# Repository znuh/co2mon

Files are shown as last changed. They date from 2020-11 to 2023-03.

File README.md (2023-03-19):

# CO2 multimon

CO2 monitor with support for different sensors, displays and microcontrollers.

Firmware and the printed circuit board include support for all of these components.
No special boards or firmware versions are needed. Sensors and the display are automatically detected by the firmware.

## Supported CO2 sensors
* SCD30
* MH-Z14A, MH-Z19B
* T67xx

## Supported displays
* 1.8" SPI TFT (ST7735 controller)
* 1.3" OLED (**must** have the following pinout: Vdd, GND, SCK, SDA - most 0.96" OLED displays will not work!)
**Note:** Try to get the 1.8" TFT instead of the OLED. OLED displays will 'burn out' after approx. 1 month of continous use. Therefor OLED support is meant as a makeshift if you cannot get the TFT.

## Supported microcontrollers

### ATMega328P 'Nano V3' Boards
For this variant you need to solder a few 0805 resistors and 3x SOT-23 components to side B of the PCB.

### STM32F042K6T6 
Fot this variant you need to solder the LQFP-32 controller, a SOT-23 component, the micro-USB connector, a 1210 fuse and a few 0603 passives to side A of the PCB.

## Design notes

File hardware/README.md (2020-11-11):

## further ideas
* add Vdd/GND labels to OLED connector
* use other micro-USB connector? (current choice is hard to solder by hand)
* 3D printed case? (might need larger PCB?)
* add-on board for temp./humidity

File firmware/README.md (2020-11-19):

# building for ATMega328P target
* make sure you have *avr-gcc + libc and binutils* installed
* run **make avr**

## flashing the ATMega328P
* make sure *avrdude* is installed
* run **avrdude -pm328p -carduino -b57600 -P /dev/ttyUSBx -Uflash:w:co2mon.hex:i** (replace ttyUSBx with your device)

# building for STM32F042K target
* make sure you have the *arm-none-eabi* toolchain installed
* get *libopencm3* with **git submodule init && git submodule update**
* build libopencm3 with **make -j8 -C libopencm3**
* run **make stm32**

## flashing the STM32
* **NOTE:** MH-Zxx sensors must be disconnected before starting the bootloader (otherwise the STM32 bootloader will try talking to the MH-Z sensor and USB will not work)
* make sure *dfu-util* is installed
* set the *BOOT_SEL* jumper (JP1) before connecting the board to your computer
* run **dfu-util -a 0 --dfuse-address 0x08000000 -D co2mon.bin**

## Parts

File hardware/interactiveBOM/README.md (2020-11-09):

# BOMs
* use **atmega328p-ibom.html** for ATMega328P variant
* use **stm32-ibom.html** for STM32 variant

**Note:** The BOMs include **all** pin sockets. You only need to place those used by your sensor and display.

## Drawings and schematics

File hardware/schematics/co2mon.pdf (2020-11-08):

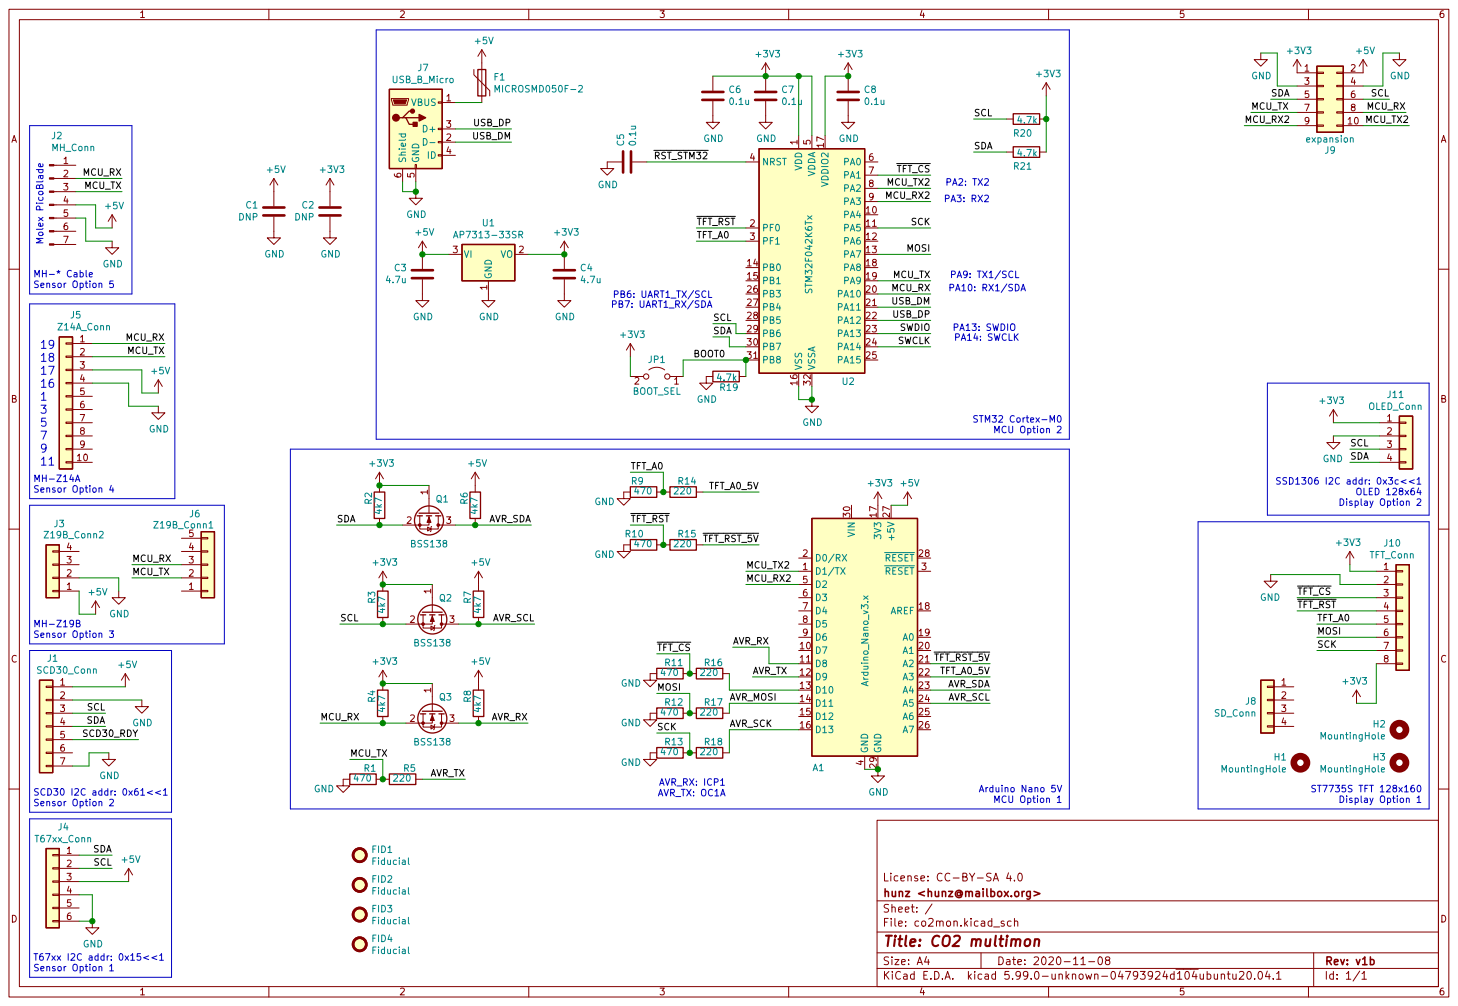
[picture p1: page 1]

1 PA4 10 PA5 11 PA6 12 PA7 13 PB0 14 PB1 15 VSS 16 VDDIO2 17 PA8 18 PA9 19 PF0 2 PA10 20 PA11 21 PA12 22 PA13 23 PA14 24 PA15 25 PB3 26 PB4 27 PB5 28 PB6 29 PF1 3 PB7 30 PB8 31 VSSA 32 NRST 4 VDDA

License: CC-BY-SA 4.0 R18

File: co2mon.kicad_sch Sheet: / hunz <hunz@mailbox.org>

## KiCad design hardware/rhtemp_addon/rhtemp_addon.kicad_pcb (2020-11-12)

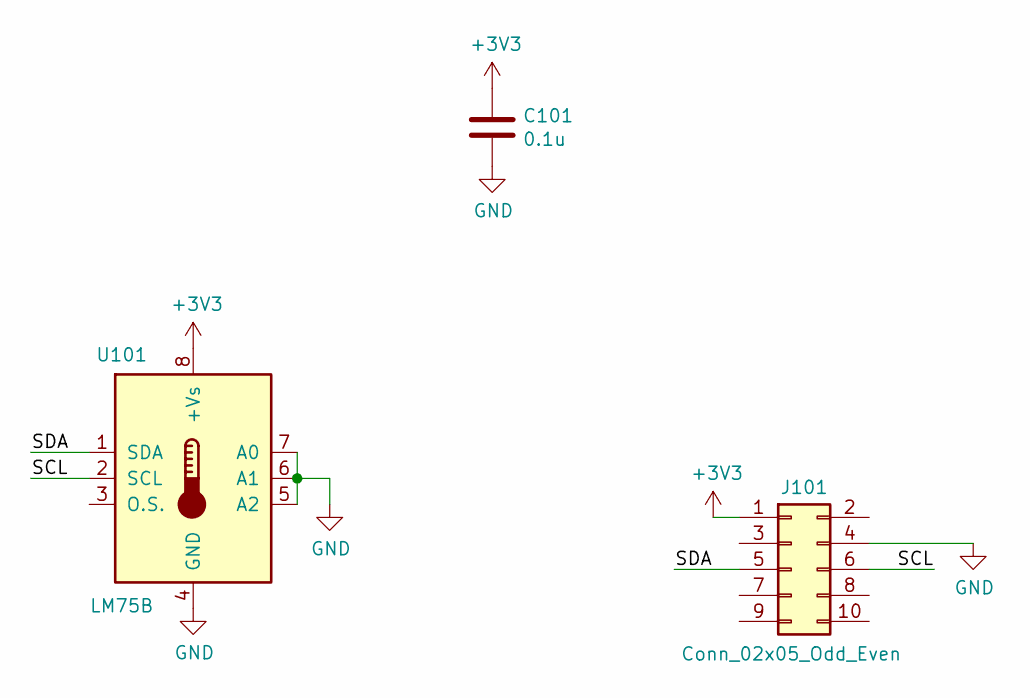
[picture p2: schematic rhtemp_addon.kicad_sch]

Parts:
C101: 0.1u; C_0603_1608Metric
J101: Conn_02x05_Odd_Even; PinSocket_2x05_P2.54mm_Vertical
U101: LM75B; SOIC-8_3.9x4.9mm_P1.27mm

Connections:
+3V3: C101.1, J101.1, U101.8 (+Vs)
/SCL: J101.6, U101.2 (SCL)
/SDA: J101.5, U101.1 (SDA)
GND: C101.2, J101.4, U101.4 (GND), U101.5 (A2), U101.6 (A1), U101.7 (A0)

Board: 2 copper layers, 3 parts (1 on the bottom side), 4 nets, no tracks yet.

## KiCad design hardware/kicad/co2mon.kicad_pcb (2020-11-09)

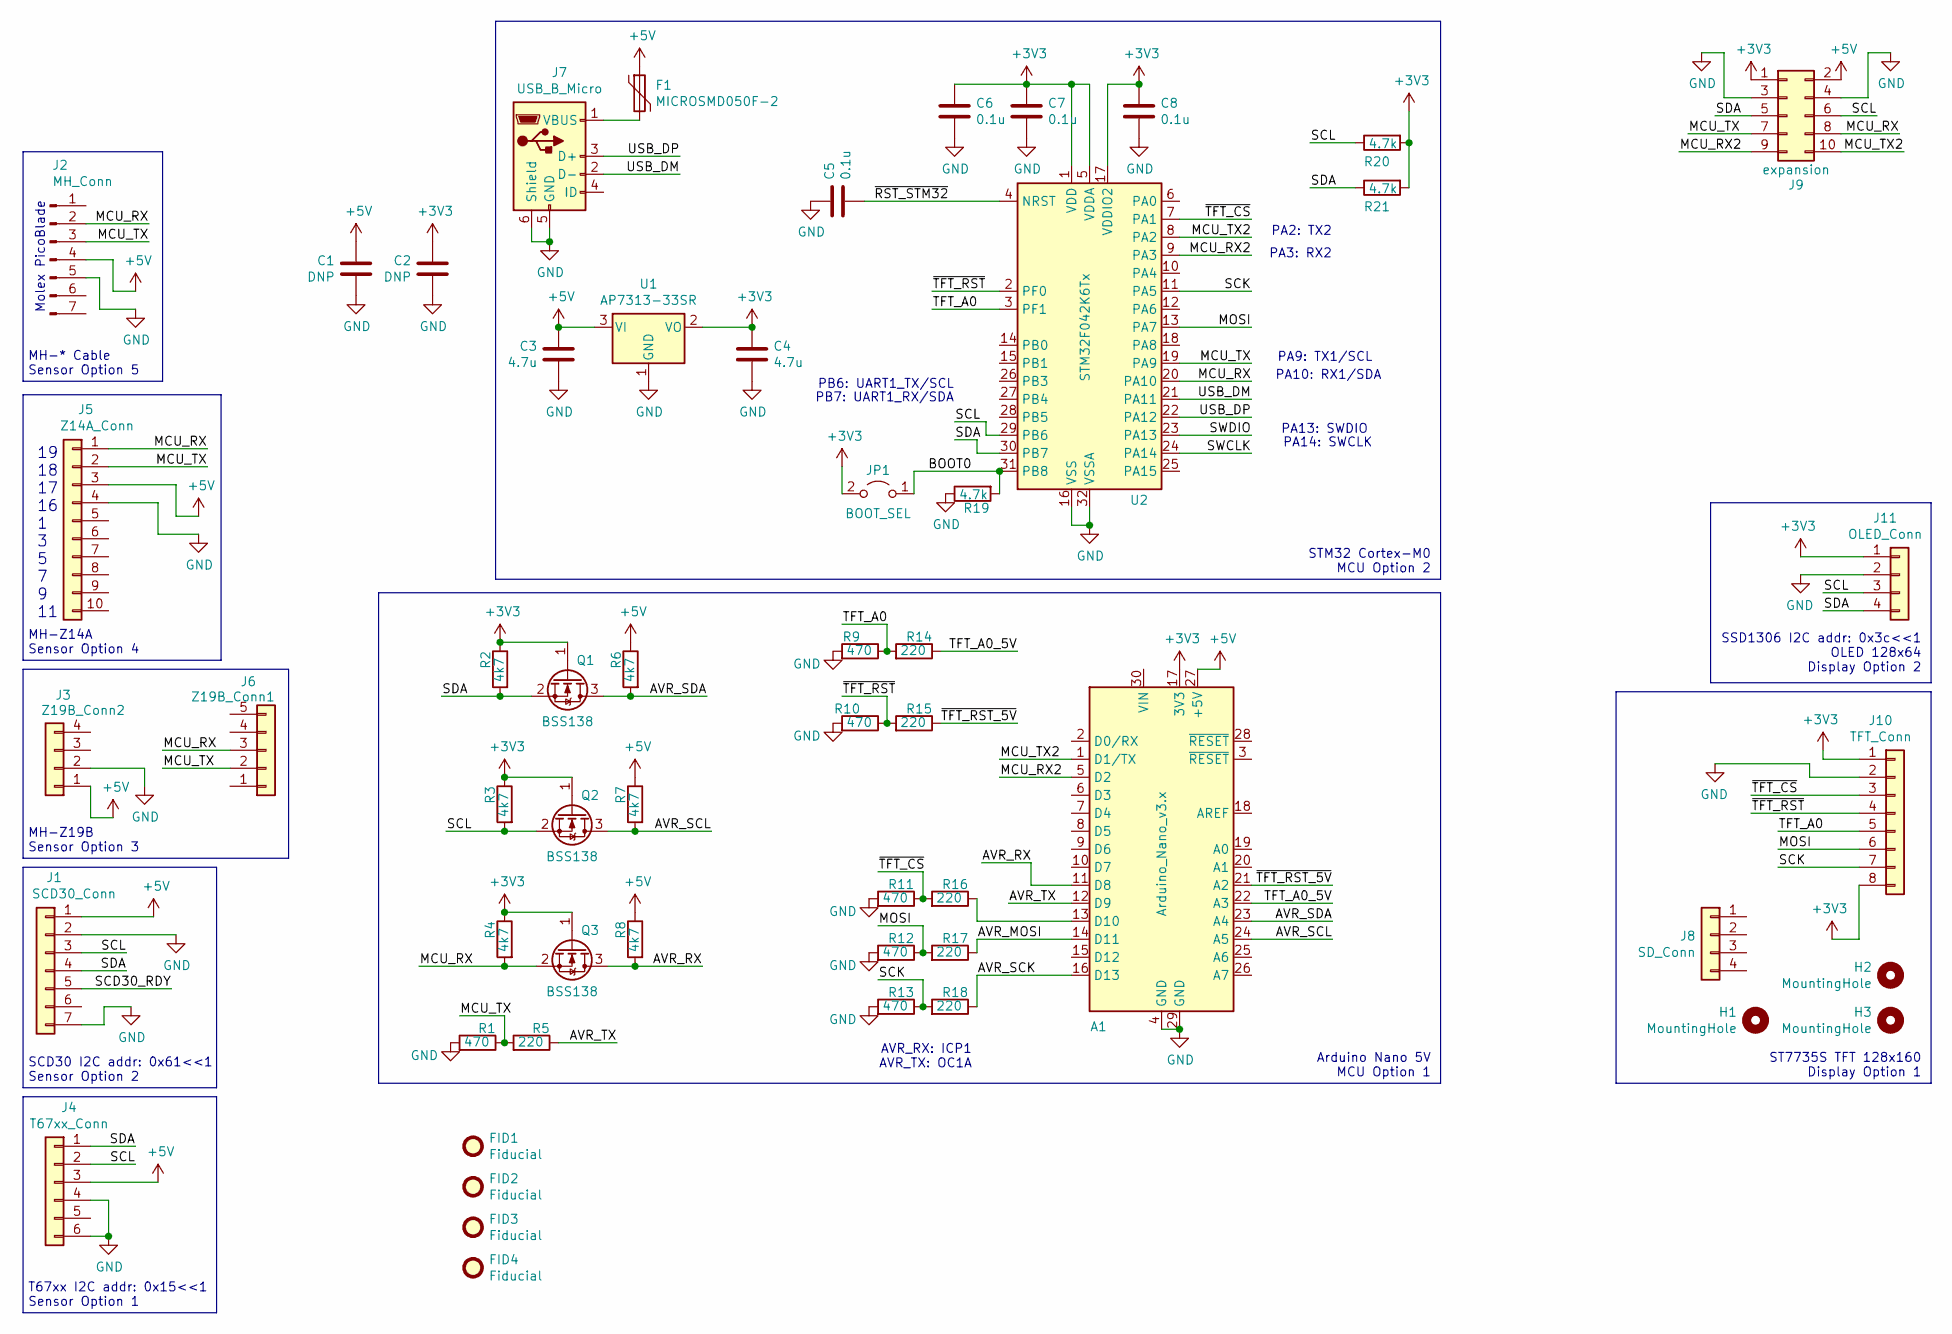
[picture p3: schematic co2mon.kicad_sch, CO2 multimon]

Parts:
A1: Arduino_Nano_v3.x; Arduino_Nano
C1, C2: DNP; C_0805_2012Metric_Pad1.15x1.40mm_HandSolder
C3, C4: 4.7u; C_0603_1608Metric
C5, C6, C7, C8: 0.1u; C_0603_1608Metric
F1: MICROSMD050F-2; Fuse_1210_3225Metric
FID1, FID2, FID3, FID4: Fiducial; Fiducial_0.5mm_Mask1.5mm
H1, H2, H3: MountingHole; MountingHole_3.2mm_M3
J1: SCD30_Conn; PinSocket_1x07_P2.54mm_Vertical
J2: MH_Conn; Molex_PicoBlade_53048-0710_1x07_P1.25mm_Horizontal
J3: Z19B_Conn2; PinSocket_1x04_P2.54mm_Vertical
J4: T67xx_Conn; PinSocket_1x06_P2.54mm_Vertical
J5: Z14A_Conn; PinSocket_1x10_P2.54mm_Vertical
J6: Z19B_Conn1; PinSocket_1x05_P2.54mm_Vertical
J7: USB_B_Micro; USB_Micro-B_Molex-105017-0001
J8: SD_Conn; PinSocket_1x04_P2.54mm_Vertical
J9: expansion; PinHeader_2x05_P2.54mm_Vertical
J10: TFT_Conn; PinSocket_1x08_P2.54mm_Vertical
J11: OLED_Conn; PinSocket_1x04_P2.54mm_Vertical
JP1: BOOT_SEL; PinHeader_1x02_P2.54mm_Vertical
Q1, Q2, Q3: BSS138; SOT-23
R1, R9, R10, R11, R12, R13: 470; R_0805_2012Metric_Pad1.15x1.40mm_HandSolder
R2, R3, R4, R6, R7, R8: 4k7; R_0805_2012Metric_Pad1.15x1.40mm_HandSolder
R5, R14, R15, R16, R17, R18: 220; R_0805_2012Metric_Pad1.15x1.40mm_HandSolder
R19, R20, R21: 4.7k; R_0603_1608Metric
U1: AP7313-33SR; SOT-23
U2: STM32F042K6Tx; LQFP-32_7x7mm_P0.8mm

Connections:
+3V3: A1.17 (3V3), C2.2, C4.2, C6.2, C7.2, C8.2, J9.1, J10.1, J10.8, J11.1, JP1.2 (B), Q1.1 (G), Q2.1 (G), Q3.1 (G), R2.1, R3.1, R4.1, R20.2, R21.2, U1.2 (VO), U2.1 (VDD), U2.5 (VDDA), U2.17 (VDDIO2)
+5V: A1.27 (+5V), C1.2, C3.2, F1.1, J1.1, J2.4, J3.1, J4.3, J5.3, J9.2, R6.1, R7.1, R8.1, U1.3 (VI)
/AVR_MOSI: A1.14 (D11), R17.1
/AVR_RX: A1.11 (D8), Q3.3 (D), R8.2
/AVR_SCK: A1.16 (D13), R18.1
/AVR_SCL: A1.24 (A5), Q2.3 (D), R7.2
/AVR_SDA: A1.23 (A4), Q1.3 (D), R6.2
/AVR_TX: A1.12 (D9), R5.1
/BOOT0: JP1.1 (A), R19.2, U2.31 (PB8)
/MCU_RX: J2.2, J5.1, J6.3, J9.8, Q3.2 (S), R4.2, U2.20 (PA10)
/MCU_RX2: A1.5 (D2), J9.9, U2.9 (PA3)
/MCU_TX: J2.3, J5.2, J6.2, J9.7, R1.1, R5.2, U2.19 (PA9)
/MCU_TX2: A1.1 (D1/TX), J9.10, U2.8 (PA2)
/MOSI: J10.6, R12.1, R17.2, U2.13 (PA7)
/SCD30_RDY: J1.5
/SCK: J10.7, R13.1, R18.2, U2.11 (PA5)
/SCL: J1.3, J4.2, J9.6, J11.3, Q2.2 (S), R3.2, R20.1, U2.29 (PB6)
/SDA: J1.4, J4.1, J9.5, J11.4, Q1.2 (S), R2.2, R21.1, U2.30 (PB7)
/SWCLK: U2.24 (PA14)
/SWDIO: U2.23 (PA13)
/TFT_A0: J10.5, R9.1, R14.2, U2.3 (PF1)
/TFT_A0_5V: A1.22 (A3), R14.1
/USB_DM: J7.2 (D-), U2.21 (PA11)
/USB_DP: J7.3 (D+), U2.22 (PA12)
/~RST_STM32: C5.1, U2.4 (NRST)
/~TFT_CS: J10.3, R11.1, R16.2, U2.7 (PA1)
/~TFT_RST: J10.4, R10.1, R15.2, U2.2 (PF0)
/~TFT_RST_5V: A1.21 (A2), R15.1
GND: A1.4 (GND), A1.29 (GND), C1.1, C2.1, C3.1, C4.1, C5.2, C6.1, C7.1, C8.1, J1.2, J1.7, J2.5, J3.2, J4.4, J4.6, J5.4, J7.5 (GND), J7.6 (Shield), J9.3, J9.4, J10.2, J11.2, R1.2, R9.2, R10.2, R11.2, R12.2, R13.2, R19.1, U1.1 (GND), U2.16 (VSS), U2.32 (VSSA)
unnamed: A1.13 (D10), R16.1
unnamed: F1.2, J7.1 (VBUS)

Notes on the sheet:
MH-* Cable Sensor Option 5
MH-Z14A Sensor Option 4
MH-Z19B Sensor Option 3
SCD30 I2C addr: 0x61<<1 Sensor Option 2
T67xx I2C addr: 0x15<<1 Sensor Option 1
19 18 17 16 1 3 5 7 9 11
Molex PicoBlade
PB6: UART1_TX/SCL
PB7: UART1_RX/SDA
AVR_RX: ICP1 AVR_TX: OC1A
PA2: TX2
PA3: RX2
PA13: SWDIO
PA9: TX1/SCL
PA14: SWCLK
PA10: RX1/SDA
STM32 Cortex-M0 MCU Option 2
Arduino Nano 5V MCU Option 1
SSD1306 I2C addr: 0x3c<<1 OLED 128x64 Display Option 2
ST7735S TFT 128x160 Display Option 1

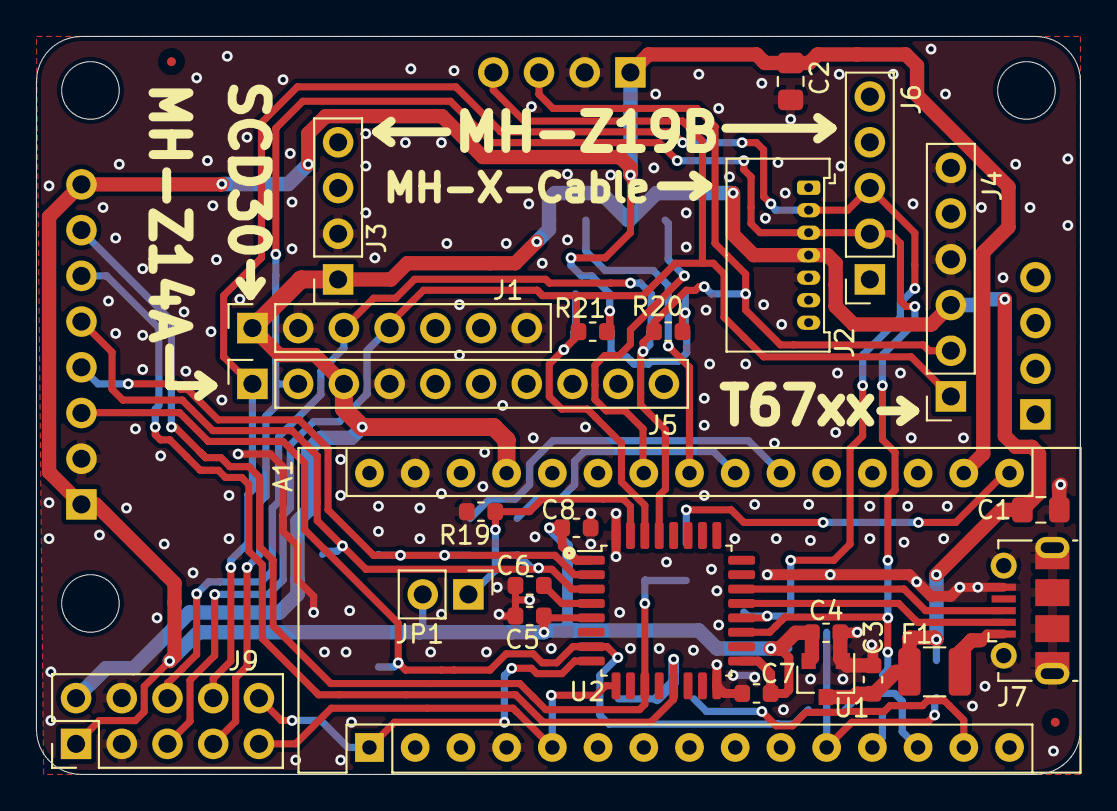
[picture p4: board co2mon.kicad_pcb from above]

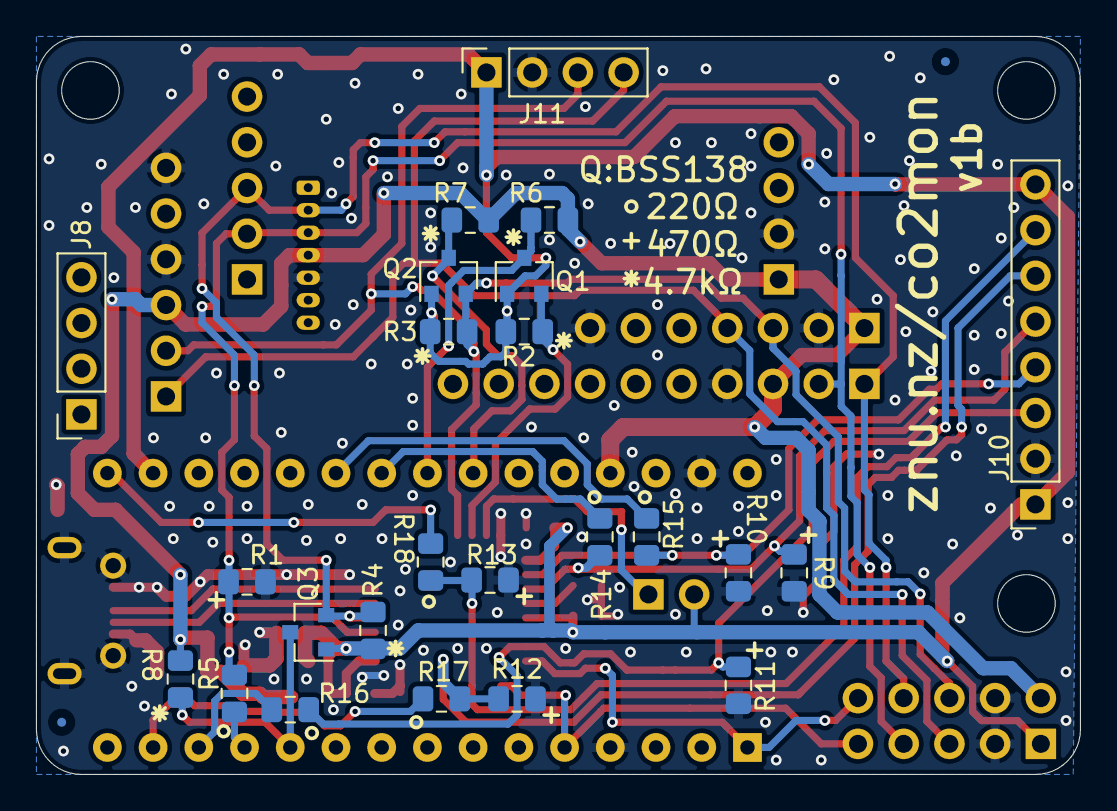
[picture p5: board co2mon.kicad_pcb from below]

Board: 2 copper layers, 58.0 x 41.0 mm, 55 parts (26 on the bottom side), 28 nets.

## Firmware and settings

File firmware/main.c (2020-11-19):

/*
 * This file is part of the co2mon project.
 *
 * Copyright (C) 2020 Benedikt Heinz <hunz@mailbox.org>
 *
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
 * You should have received a copy of the GNU General Public License
 * along with this code.  If not, see <http://www.gnu.org/licenses/>.
 */
#include "platform.h"
#include "sensors.h"
#include "display.h"
#include "utils.h"
#include <string.h>

/* maximum string length for both displays is 13 chars 
 * maximum number of lines for both displays is *4* */
#define PROJECT_STRING    "znu.nz/co2mon"
/* length of platform string (defined in Makefile) must be <= 10,
 * firmware string length must be <= 10 */
#define FIRMWARE_STRING   "v0.1-rc3"

static void print_info(void) {
	char display[14]="display: ";
	char sensors[3][14]={"","",""};
	char *lines[8]={
		PROJECT_STRING,
		"hw:" PLATFORM_STRING,
		"fw:" FIRMWARE_STRING,
		display,
		"sensors:",
		sensors[0],
		sensors[1],
		sensors[2]
	};
	const char *sn;
	uint8_t i;
	display_getname(display+9);
	/* get list of sensors */
	for(i=0;(i<3)&&(sn=sensors_getname(i));i++) {
		strncpy(sensors[i]+1,sn,12);
		sensors[i][0]='+';
		sensors[i][13]=0;
	}
	/* display - split into multiple pages if necessary */
	for(i=0;i<8;) {
		i+=display_showtext(lines+i, 8-i);
		msleep(5000);
	}
	/* also output info via system UART */
	for(i=0;i<8;i++) {
		uart_tx(UART_SYS_CH, lines[i], strlen(lines[i]));
		uart_tx(UART_SYS_CH, "\r\n", 2);
	}
}

static void serial_printvals(readings_t *v) {
	if(CO2_VALID(v)) {
		char buf[16]="CO2: xxxx ppm ";
		i16_to_dec(v->co2,buf+5,4,-1,0);
		uart_tx(UART_SYS_CH, buf, strlen(buf));
	}
	if(TEMP_VALID(v)) {
		char buf[16]="temp: +99°C ";
		i16_to_dec(v->temperature,buf+6,3,-1,0);
		uart_tx(UART_SYS_CH, buf, strlen(buf));
	}
	if(RELH_VALID(v)) {
		char buf[16]="relh: xxx% ";
		i16_to_dec(v->relh,buf+6,3,-1,0);
		uart_tx(UART_SYS_CH, buf, strlen(buf));
	}
	uart_tx(UART_SYS_CH, "\r\n", 2);
}

/* TODOs:
 * - use watchdog?
 */
int main(int argc, char **argv) {
	readings_t vals;

	hw_init(argc, argv);
	msleep(100); /* wait a bit for sensors to come up after poweron */

	display_init();
	sensors_init();

	print_info();

	while(1) {
		sensors_read(&vals);
		display_update(&vals);
		serial_printvals(&vals);
		msleep(5000);
	}

	return 0;
}

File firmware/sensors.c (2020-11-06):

/*
 * This file is part of the co2mon project.
 *
 * Copyright (C) 2020 Benedikt Heinz <hunz@mailbox.org>
 *
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
 * You should have received a copy of the GNU General Public License
 * along with this code.  If not, see <http://www.gnu.org/licenses/>.
 */
#include "platform.h"
#include "sensors.h"
#include "sensor.h"
#include "utils.h"
#include <string.h>

//#define DEBUG

#ifdef DEBUG
#include <stdio.h>
#endif

int t67xx_init(uint8_t addr);
int t67xx_read(uint8_t addr, readings_t *vals);

int hih6x_init(uint8_t addr);
int hih6x_read(uint8_t addr, readings_t *vals);

int lm75_init(uint8_t addr);
int lm75_read(uint8_t addr, readings_t *vals);

int scd30_init(uint8_t addr);
int scd30_read(uint8_t addr, readings_t *vals);

int shtc3_init(uint8_t addr);
int shtc3_read(uint8_t addr, readings_t *vals);

int mhzxx_init(uint8_t addr);
int mhzxx_read(uint8_t addr, readings_t *vals);

/* if values for temp/rhel/co2 are provided by multiple
 * sensors, sensors later in this list "win"
 * b/c they overwrite the values provided by
 * previous sensors. */
static const sensor_t sensors[] = {
	{
		.iface = IFACE_UART,
		.addr  = 0,
		.name  = "MH-Zxx",    /* MH-Z14A, MH-Z19B: CO2 only */
		.init  = mhzxx_init,
		.read  = mhzxx_read,
	},
	/* temperature of SCD30 doesn't seem to be too accurate
	 * therefor we move it up in this list */
	{
		.iface = IFACE_I2C,
		.addr  = 0x61,
		.name  = "SCD30",     /* CO2, temperature, humidity */
		.init  = scd30_init,
		.read  = scd30_read,
	},
	/* move SHTC3 up in this list
	 * b/c it's heated a bit by the co2mon PCB
	 * when mounted directly on the PCB */
	{
		.iface = IFACE_I2C,
		.addr  = 0x70,
		.name  = "SHTC3",     /* temperature, humidity */
		.init  = shtc3_init,
		.read  = shtc3_read,
	},
	{
		.iface = IFACE_I2C,
		.addr  = 0x15,
		.name  = "T67xx",     /* CO2 only */
		.init  = t67xx_init,
		.read  = t67xx_read,
	},
	{
		.iface = IFACE_I2C,
		.addr  = 0x27,
		.name  = "HIH6x",     /* temperature, humidity */
		.init  = hih6x_init,
		.read  = hih6x_read,
	},
	{
		.iface = IFACE_I2C,
		.addr  = 0x48,
		.name  = "LM75",     /* temperature */
		.init  = lm75_init,
		.read  = lm75_read,
	},
	{
		.iface = 0,
		.addr  = 0,
		.name  = "",
		.init  = NULL,
		.read  = NULL,
	}
};

#define MAX_SENSORS        3 /* CO2, temp, humidity */
static uint8_t avail_sensors[MAX_SENSORS];
static uint8_t n_sensors = 0;

int sensors_init(void) {
	int i;
	for(i=0;(n_sensors<MAX_SENSORS) && sensors[i].iface;i++) {
		const sensor_t *s = sensors+i;
		int res = 0;
		if(s->iface == IFACE_I2C) {
			uint8_t ping;
			res = i2c_xfer(s->addr, NULL, 0, &ping, 1);
#ifdef DEBUG
			printf("i2c probe %s@%02x: %d\n",s->name,s->addr,res);
#endif
			if(res < 1)
				continue;
		}
		res = s->init(s->addr);
#ifdef DEBUG
		printf("%s@%02x: init: %d\n",s->name,s->addr,res);
#endif
		if(res < 1)
			continue;
#ifdef DEBUG
		printf("sensor %s found\n",s->name);
#endif /* DEBUG */
		avail_sensors[n_sensors++] = i;
	}
	return n_sensors;
}

int sensors_read(readings_t *vals) {
	int i;

	vals->co2         = CO2_INVALID;
	vals->temperature = TEMP_INVALID;
	vals->relh        = RELH_INVALID;
	
	for(i=0;i<n_sensors;i++) {
		const sensor_t *s = sensors + avail_sensors[i];
		s->read(s->addr, vals);
	}

#ifdef DEBUG
	printf("CO2: %d ppm, temp: %d°C, rh: %d%%\n", vals->co2, vals->temperature, vals->relh);
#endif /* DEBUG */

	return 0;
}

const char *sensors_getname(uint8_t i) {
	return (i<n_sensors) ? sensors[avail_sensors[i]].name : NULL;
}

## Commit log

2020-11-03 working on stm32, fix some compiler warnings
    [mhzxx.c]
2020-11-03 more compiler warning fixes
    [oled.c, tft.c]
2020-11-03 add non-stm32 targets to new common Makefile
2020-11-03 add firmware size info for stm32
2020-11-03 rename gpio_set to avoid namespace collisions w/ libopencm3, start working on stm32 code
    [atmega328p.c, linux.c, platform.h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]
2020-11-03 add stm32 IO assignments
2020-11-03 stm32: WIP
2020-11-03 respect jiffies uint32 rollover case
2020-11-03 stm32 UART
2020-11-03 msleep(10) in AVR hw_init no longer needed w/ msleep(100) after hw_init in main
    [atmega328p.c]
2020-11-03 more i2c init stuff
2020-11-03 working on stm32 i2c
2020-11-03 dfu-util command for stm32 firmware upload
2020-11-03 msleep must wait at least 1 increment longer b/c current timer cycle has already started
2020-11-03 fixes for stm32 gpio init
2020-11-03 fixes for SPI and UART - SPI+UART working on STM32
2020-11-04 working on stm32 i2c code
2020-11-04 stm32 i2c wip
2020-11-04 stm32 i2c write
2020-11-05 switch to software i2c implementation - due to i2c peripheral errata listed in ES0243 rev 3
2020-11-05 software i2c WIP
2020-11-05 fix for stupid bug in stm32 software i2c
2020-11-05 do proper crc checks for SHTC3 sensor
2020-11-05 i2c timings tuned a bit
2020-11-05 stm32 works
2020-11-06 new timeout code w/ timer rollover handling
2020-11-06 fix for timeout code
    [atmega328p.c, main.c]
2020-11-06 move SHTC3 to top of sensors list
2020-11-06 i2c timeout fix for atmega328p
    [atmega328p.c]
2020-11-06 reorder sensors list
2020-11-08 always print 'ppm CO2' string on OLED, use stdout on linux
2020-11-08 remove remnants of stm32 i2c peripheral
2020-11-08 revert previous "fix" for OLED display - doesn't fix the actual problem
    [oled.c]
2020-11-08 initial import
    [co2mon.kicad_pcb, co2mon.kicad_sch]
2020-11-08 add note about kicad-nightly
2020-11-08 remove temp/humidity sensor
    [co2mon.kicad_pcb, co2mon.kicad_sch]
2020-11-08 add schematics and gerber files
    [co2mon-B_Cu.gbr, co2mon-B_Mask.gbr, co2mon-B_Paste.gbr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]
2020-11-09 update BOM exclusions
    [co2mon.kicad_pcb]
2020-11-09 AVR timeout bug fixed - bump version
    [main.c]
2020-11-12 working on rh/temp addon board
    [rhtemp_addon.kicad_pcb, rhtemp_addon.kicad_sch]
2020-11-15 working on stm32 usb data output
2020-11-15 stm32 usb wip
2020-11-15 support switching back to bootloader via USB
2020-11-19 make stm32 bootloader invocation more robust, add stm32 USB tx, bump version to -rc3
2020-11-23 make flashing stm32 work when already in bootloader
2023-06-14 don't pull I2C low on init

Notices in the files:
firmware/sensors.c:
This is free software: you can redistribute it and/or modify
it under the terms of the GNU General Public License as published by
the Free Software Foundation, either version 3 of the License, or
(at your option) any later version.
